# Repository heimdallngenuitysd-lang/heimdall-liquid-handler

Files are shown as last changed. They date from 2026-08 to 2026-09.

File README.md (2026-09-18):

Heimdall is a low-cost, open-source automated liquid-handling platform developed by repurposing a Creality Ender-series FDM 3D printer. The system retains the printer's Cartesian motion architecture while integrating a modular 3D-printed pipetting mechanism, an ESP32-based actuator controller, and host-side software for automated liquid-handling workflows.

A key feature of Heimdall is its vision-language model (VLM)-based closed-loop pipette-volume verification system. A camera captures the pipette volume display, and the VLM interprets the displayed setting. If the measured state differs from the requested target, the system automatically applies corrective actuation and repeats the verification process until the target setting is reached.

The platform supports:

Automated Cartesian positioning using G-code and the existing printer controller.
Programmable pipette-volume adjustment using the repurposed extruder stepper motor.
Automated aspiration, dispensing, blowout, and plunger control using an ESP32 and TB6612FNG motor driver.
Closed-loop visual verification and correction of pipette volume settings using Gemini 2.5 Flash.
Interchangeable fixtures for pipettes, labware, pipette tips, and camera positioning.
Host-side control through a Python-based graphical user interface.

The repository contains the software, firmware, control scripts, hardware-related files, and supporting documentation required to reproduce and operate the Heimdall liquid-handling platform.

Heimdall was developed as an accessible automation platform for laboratory workflows and as a foundation for integration into modular and self-driving laboratory systems.

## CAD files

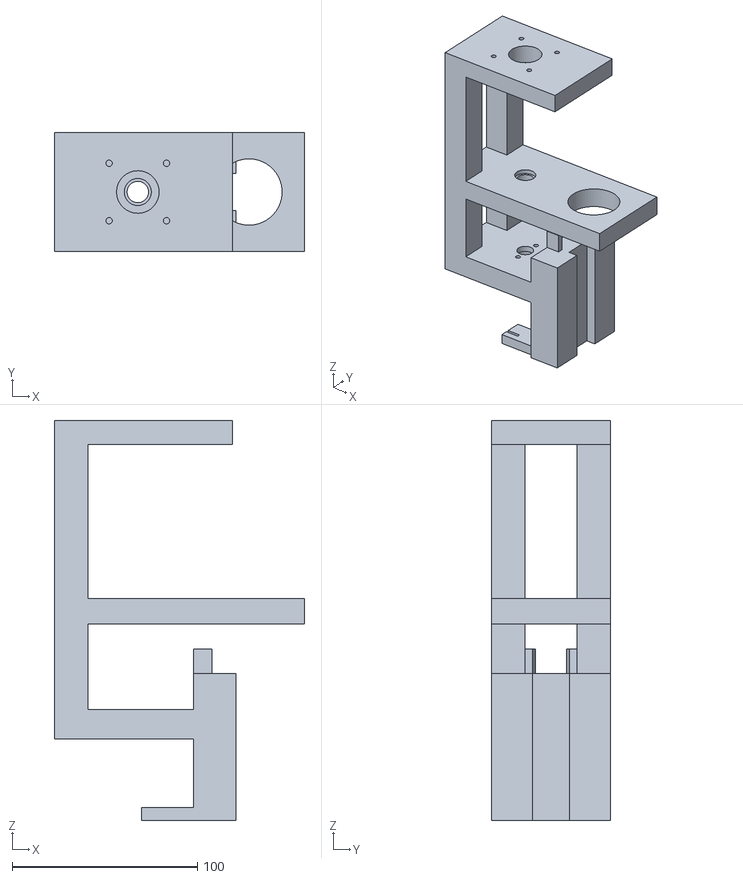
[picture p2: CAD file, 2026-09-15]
Hardware/3D Printing Files/Frame.stl
135.0 x 64.0 x 216.0

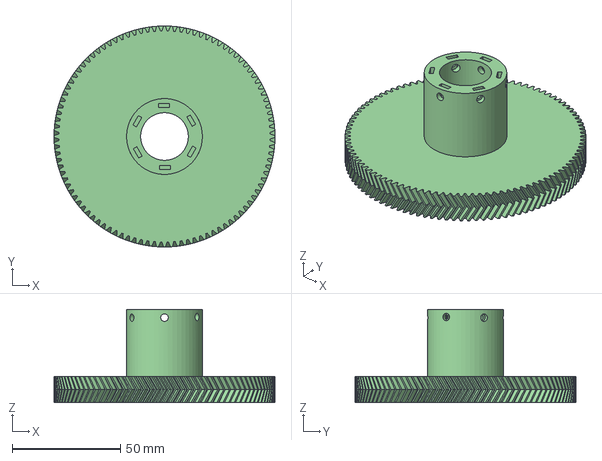
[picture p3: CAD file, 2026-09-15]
Hardware/Design Files/Driven Gear.step
102.0 x 102.0 x 43.0 mm

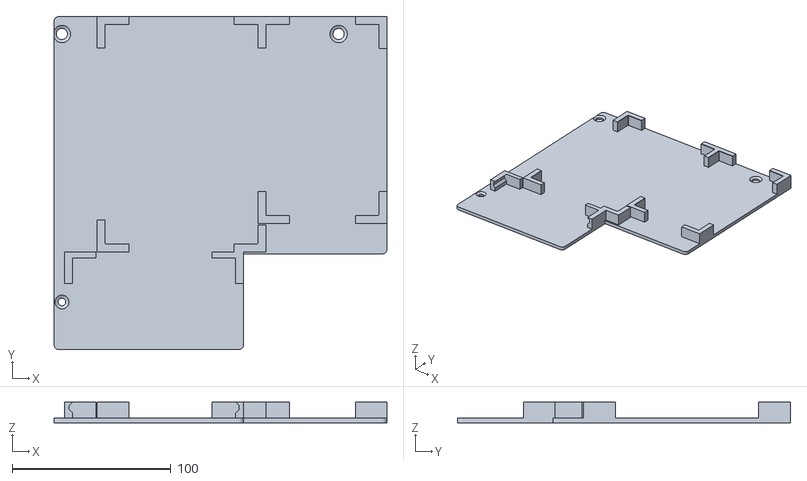
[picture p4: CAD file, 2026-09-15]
Hardware/3D Printing Files/Bed Plate.stl
210.0 x 210.1 x 13.0

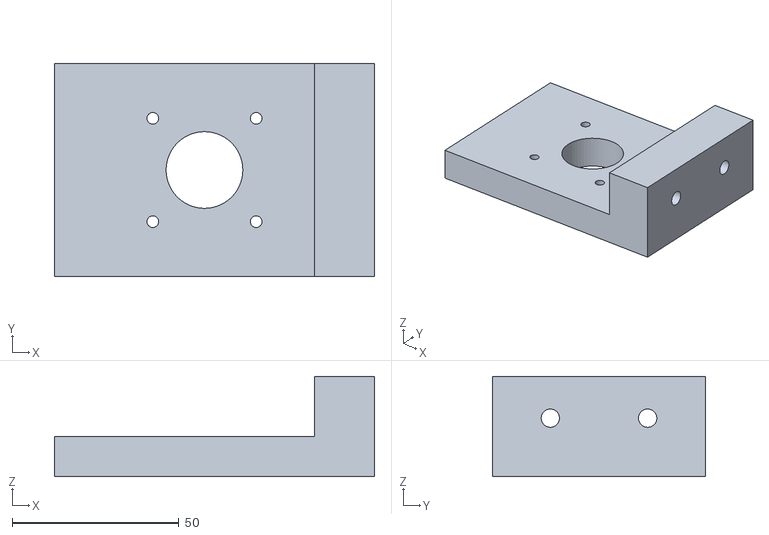
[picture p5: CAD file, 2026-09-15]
Hardware/3D Printing Files/Top Mounting Plate.stl
96.0 x 64.0 x 30.0

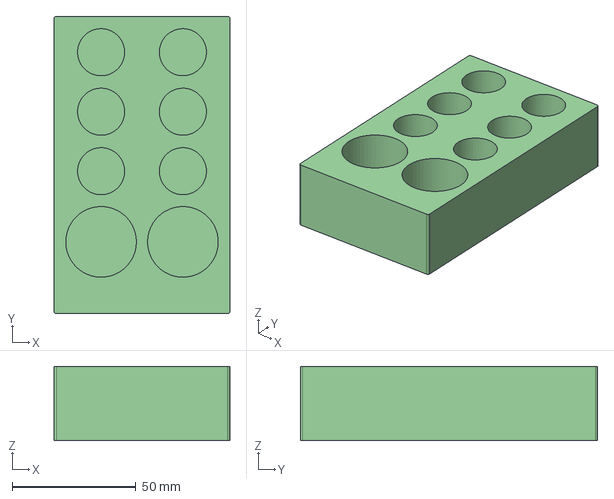
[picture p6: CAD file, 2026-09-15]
Hardware/Design Files/Stock Solution Holder.step
71.0 x 120.0 x 30.0 mm

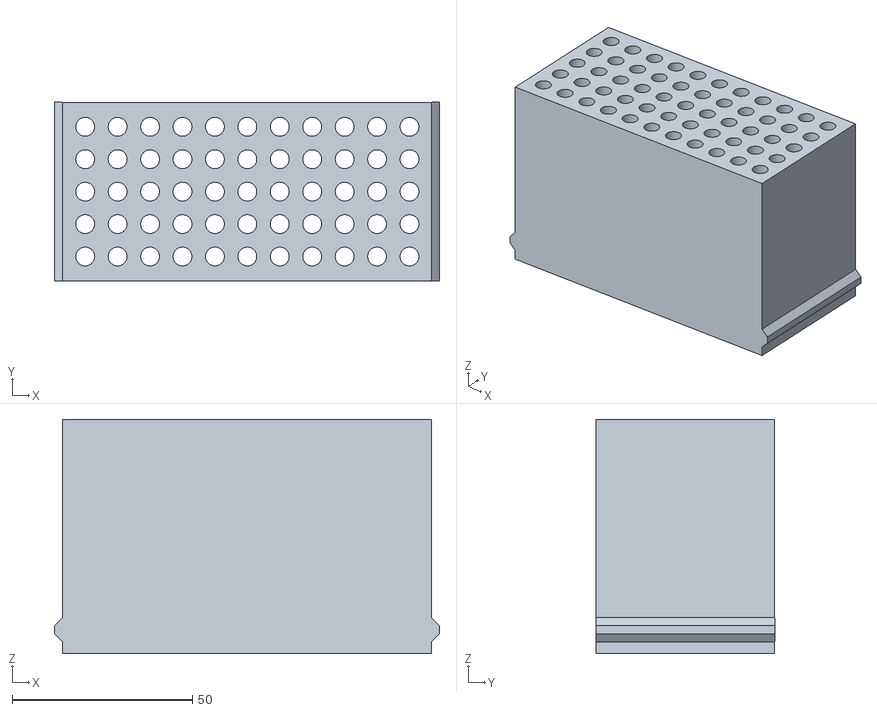
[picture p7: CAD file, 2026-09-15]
Hardware/3D Printing Files/Pipette Holder for 200microliter tips.stl
106.8 x 49.8 x 65.0

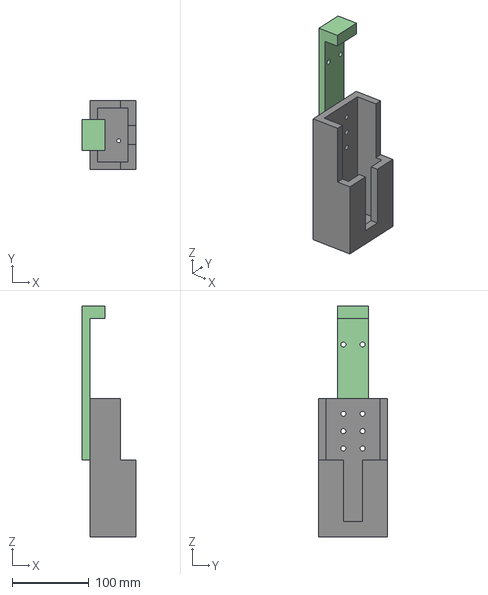
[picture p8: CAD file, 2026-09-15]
Hardware/Design Files/Pipette Tip Disposal Chamber Unit.step
70.0 x 90.0 x 300.0 mm
Tip ejector part
Disposal chamber

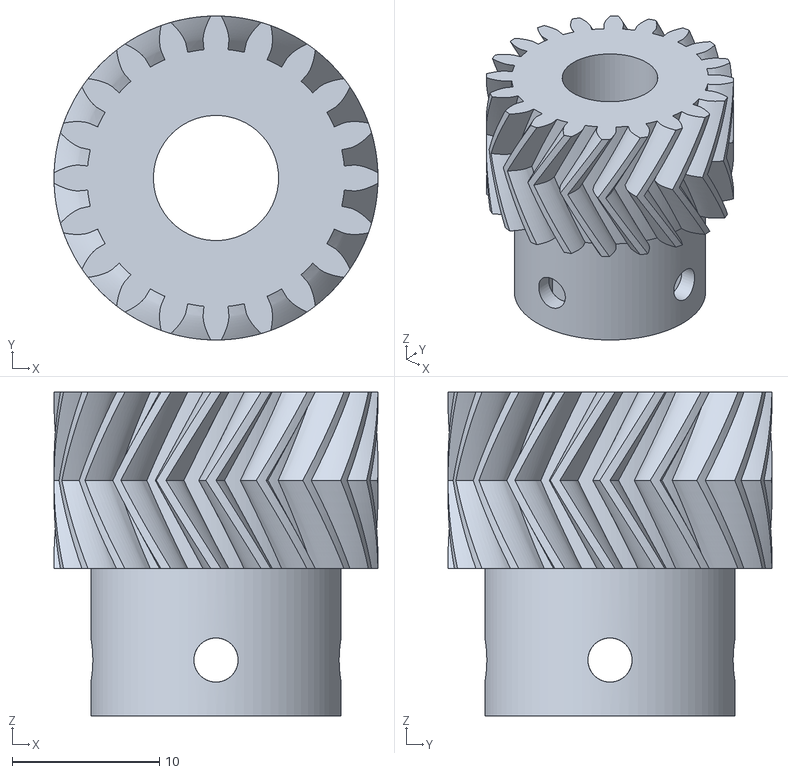
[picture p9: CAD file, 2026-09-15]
Hardware/3D Printing Files/Driver Gear.stl
22.0 x 22.0 x 22.0

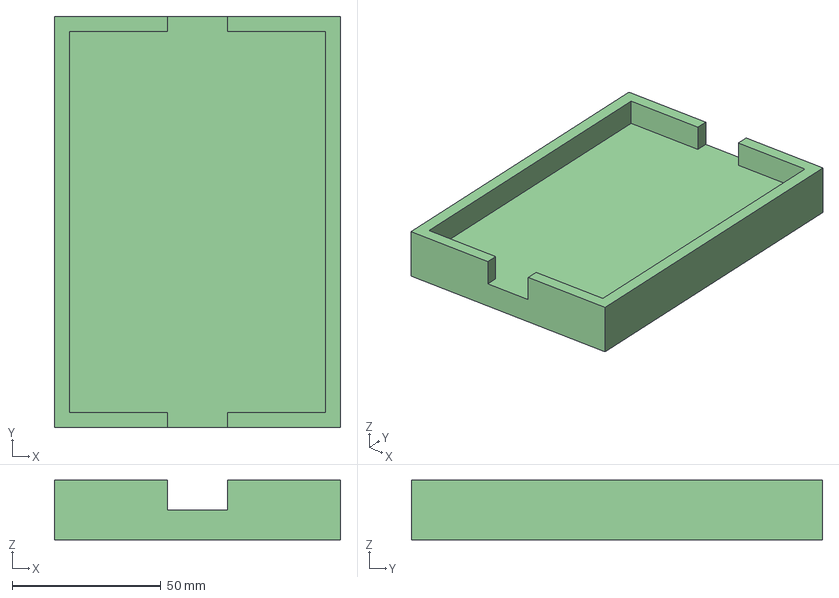
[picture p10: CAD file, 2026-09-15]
Hardware/Design Files/96 Well Plate Holder.step
96.0 x 138.0 x 20.0 mm

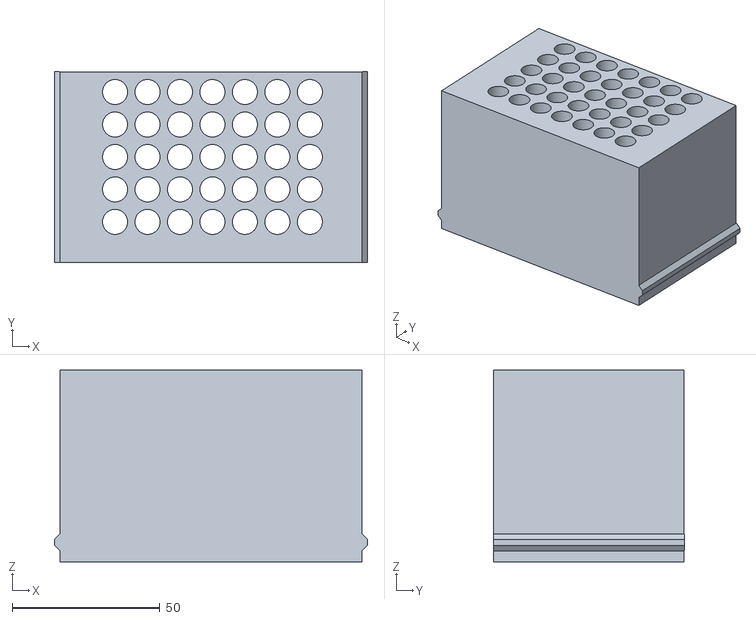
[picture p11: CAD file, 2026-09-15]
Hardware/3D Printing Files/Pipette Holder for 1000microliter tips.stl
106.0 x 64.8 x 65.0

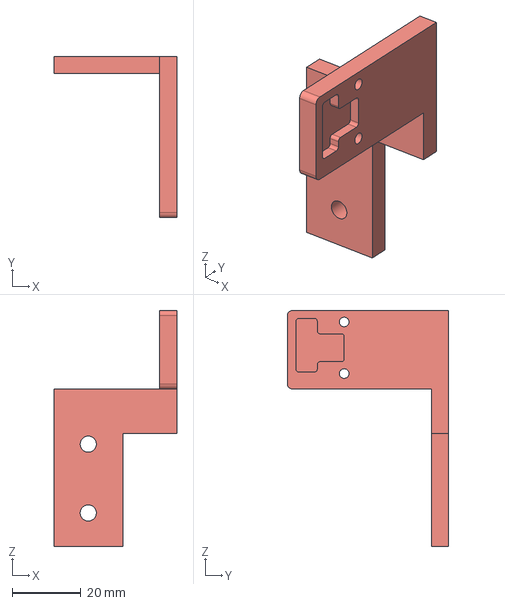
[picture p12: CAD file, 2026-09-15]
Hardware/Design Files/Z axis Limit Switch Holder.step
35.6 x 46.9 x 68.6 mm

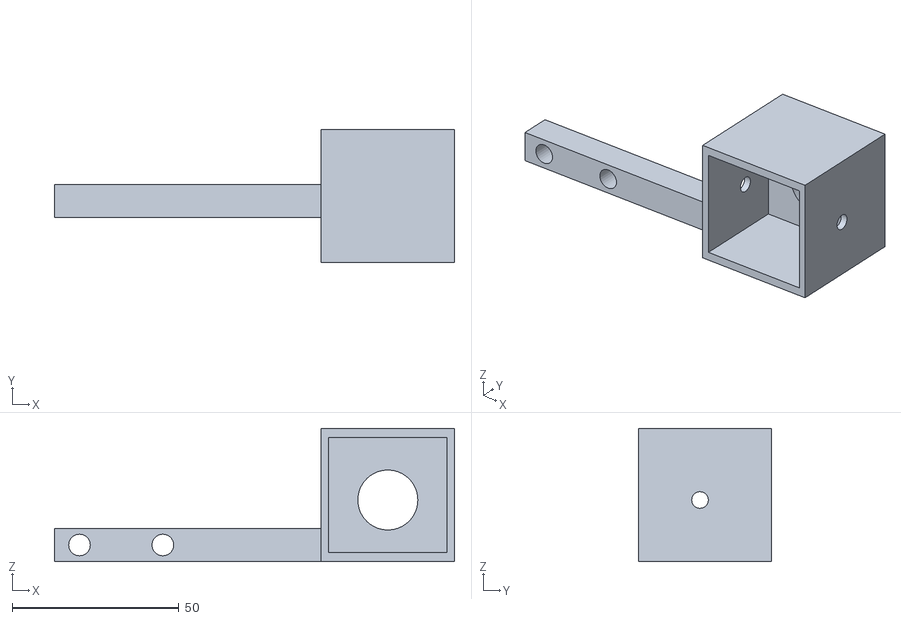
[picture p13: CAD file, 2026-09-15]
Hardware/3D Printing Files/Camera Mount.stl
120.0 x 40.0 x 40.0

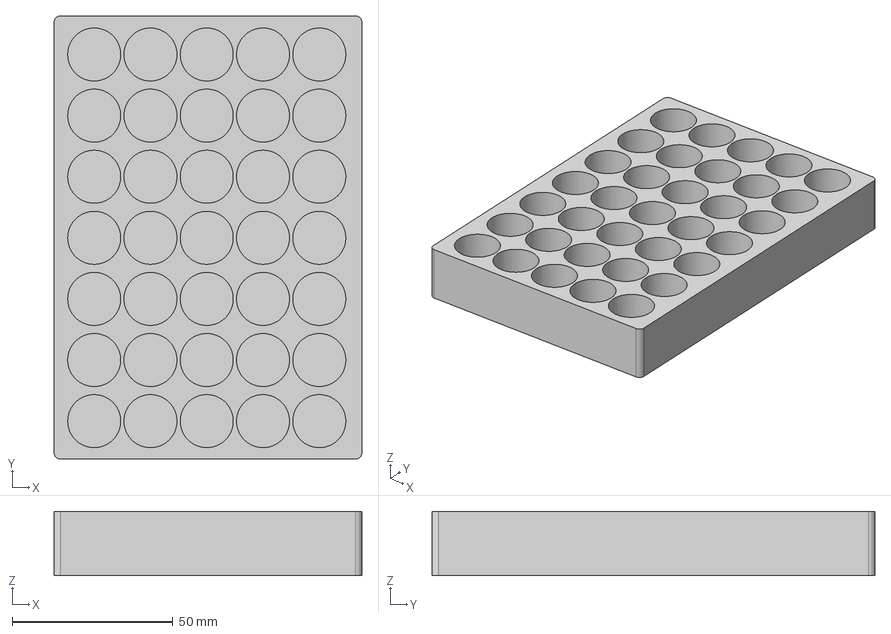
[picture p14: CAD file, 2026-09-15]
Hardware/Design Files/4ml Vial Holder.step
95.8 x 137.8 x 20.0 mm

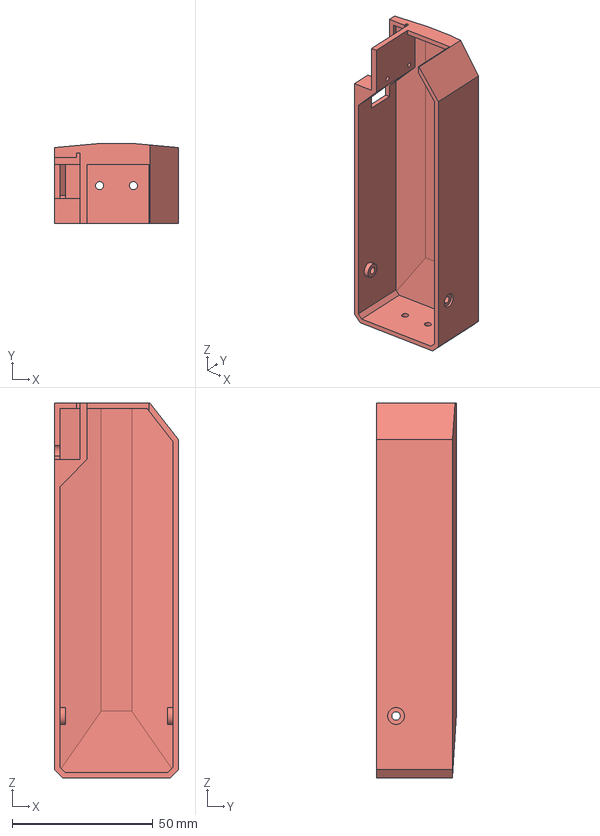
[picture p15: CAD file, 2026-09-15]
Hardware/Design Files/X axis Limit Switch Holder.step
44.0 x 28.5 x 133.0 mm

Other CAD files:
Hardware/Design Files/Frame.step
Hardware/3D Printing Files/Pipette Tip Disposal Chamber Unit (Tip Ejector Part).stl
Hardware/Design Files/Bed Plate.step
Hardware/3D Printing Files/Stock Solution Holder.stl
Hardware/3D Printing Files/4ml Vial Holder.stl
Hardware/3D Printing Files/96 Well Plate Holder.stl
Hardware/3D Printing Files/Driven Gear.stl
Hardware/3D Printing Files/Holder for 15ml Falcon tubes and 2ml Centrifuge tubes.stl
Hardware/3D Printing Files/Pipette Tip Disposal Chamber Unit (Disposal Chamber).stl
Hardware/3D Printing Files/X axis Limit Switch Holder.stl
Hardware/3D Printing Files/Z axis Limit Switch Holder.stl
Hardware/Design Files/Camera Mount.step
Hardware/Design Files/Driver Gear.step
Hardware/Design Files/Holder for 15ml Falcon tubes and 2ml Centrifuge tubes.step
Hardware/Design Files/Pipette Holder for 1000microliter tips.step
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

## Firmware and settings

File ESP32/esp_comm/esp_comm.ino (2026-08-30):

#include <ArduinoJson.h>

const int ENA  = 23;
const int AIN1 = 14;
const int AIN2 = 22;

// ESP32 PWM
const int pwmChannel = 0;
const int pwmFreq = 5000;
const int pwmResolution = 8;   // 0-255
int last_id = -1;

// Watchdog timer
unsigned long lastCommandTime = 0;
const unsigned long TIMEOUT_MS = 7000;

// Global speed
int currentPwmSpeed = 255;

void coastStop() {
  ledcWrite(ENA, 0);
  digitalWrite(AIN1, LOW);
  digitalWrite(AIN2, LOW);
}

void extendStart() {
  digitalWrite(AIN1, HIGH);
  digitalWrite(AIN2, LOW);
  ledcWrite(ENA, currentPwmSpeed);
}

void retractStart() {
  digitalWrite(AIN1, LOW);
  digitalWrite(AIN2, HIGH);
  ledcWrite(ENA, currentPwmSpeed);
}

void extendFor(uint32_t ms) {
  extendStart();
  delay(ms);
  coastStop();
}

void retractFor(uint32_t ms) {
  retractStart();
  delay(ms);
  coastStop();
}

bool verifyChecksum(const String& rawJson) {
    String json = rawJson;
    json.trim();

    // Find "checksum":
    int keyPos = json.indexOf("\"checksum\"");
    if (keyPos < 0) {
        Serial.println("Missing checksum key");
        return false;
    }

    int colonPos = json.indexOf(':', keyPos);
    if (colonPos < 0) {
        Serial.println("Malformed checksum field");
        return false;
    }

    // Skip whitespace
    int valueStart = colonPos + 1;
    while (valueStart < json.length() && isspace(json[valueStart])) {
        valueStart++;
    }

    // Read numeric checksum
    int valueEnd = valueStart;
    while (valueEnd < json.length() && isdigit(json[valueEnd])) {
        valueEnd++;
    }

    if (valueStart == valueEnd) {
        Serial.println("Invalid checksum value");
        return false;
    }

    int receivedChecksum = json.substring(valueStart, valueEnd).toInt();

    // Replace checksum digits with 0
    String modified =
        json.substring(0, valueStart) +
        "0" +
        json.substring(valueEnd);

    String calculatedHex = calculateChecksum(modified);

    char receivedHex[3];
    sprintf(receivedHex, "%02X", receivedChecksum);

    return calculatedHex.equalsIgnoreCase(receivedHex);
}

String calculateChecksum(const String& data) {
    uint8_t checksum = 0;

    for (size_t i = 0; i < data.length(); i++) {
        checksum ^= (uint8_t)data[i];
    }

    char buf[3];
    sprintf(buf, "%02X", checksum);

    return String(buf);
}

void sendJsonWithChecksum(JsonDocument& doc) {
    doc["checksum"] = 0;

    String payload;
    serializeJson(doc, payload);

    String checksumHex = calculateChecksum(payload);

    // If your protocol uses decimal checksum:
    doc["checksum"] = strtol(checksumHex.c_str(), nullptr, 16);

    payload = "";
    serializeJson(doc, payload);

    Serial.println(payload);
}

void setup() {
  Serial.begin(115200);

  pinMode(AIN1, OUTPUT);
  pinMode(AIN2, OUTPUT);

  // ESP32 PWM setup
  ledcAttach(ENA, pwmFreq, pwmResolution);

  retractStart();
  lastCommandTime = millis();

  // let boot messages finish
  delay(500);

  // clear any leftover junk (optional but helpful)
  while (Serial.available()) {
    Serial.read();
  }

  // READY handshake (MUST be JSON only)
  Serial.println("{\"status\":\"ready\"}");

}


void loop() {
  if (Serial.available()) {
    String msg = Serial.readStringUntil('\n');

    StaticJsonDocument<128> doc;
    DeserializationError err = deserializeJson(doc, msg);

    if (err) {
        return;  // Can't even determine the id
    }

    int id = doc["id"] | -1;

    if (!verifyChecksum(msg)) {
    StaticJsonDocument<64> ack;
    ack["ack"] = id;
    ack["status"] = "ok";
    ack["ok"] = false;

    sendJsonWithChecksum(ack);
    return;
    }

    StaticJsonDocument<64> ack;
    ack["ack"] = id;
    ack["status"] = "ok";
    ack["ok"] = true;

    sendJsonWithChecksum(ack);

    if (id == -1 | id <= last_id){
      return;
    }


    lastCommandTime = millis();

    bool direction = doc["direction"];   // true = extend
    uint32_t runTime = doc["time"];
    int speedPct = doc["speed"];

    speedPct = constrain(speedPct, 0, 100);
    currentPwmSpeed = map(speedPct, 0, 100, 0, 255);

    if (direction && runTime) {
      extendFor(runTime);
    } else {
      if (runTime) {
        retractFor(runTime);
      } else {
        retractStart();
      }
    }

    StaticJsonDocument<128> reply;
    reply["status"] = "ok";
    reply["direction"] = direction;
    reply["runtime"] = runTime;
    reply["id"] = id;

    sendJsonWithChecksum(reply);
    Serial.println();
    lastCommandTime = millis();
  }

  // watchdog: auto retract after no messages
  if (millis() - lastCommandTime >= TIMEOUT_MS) {
    currentPwmSpeed = 255;
    retractStart();
  }
}

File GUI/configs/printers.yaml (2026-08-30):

alfred:
  aspiration_actuation_time: 1120
  blowout_actuation_time: 400
  blowout_pause_time: 2000
  decimal_position: 0
  dispense_dwell_time: 2000
  dispose_actuate_z: 11
  dispose_initial_y: 15
  dispose_initial_z: 70
  dispose_start:
  - 150
  - 85
  - 246
  dispose_y: 17
  extruder: true
  max_vol: 1000
  min_vol: 100
  preset: null
  prime_dwell_time_after: 1000
  prime_dwell_time_before: 1
  vol_adjust_position:
  - 83.4
  - 65.0
  - 196.5
heimdall:
  aspiration_actuation_time: 1120
  blowout_actuation_time: 300
  blowout_pause_time: 2000
  decimal_position: 1
  dispense_dwell_time: 1600
  dispose_actuate_z: 11
  dispose_initial_y: 15
  dispose_initial_z: 70
  dispose_start:
  - 160
  - 85
  - 246
  dispose_y: 18
  extruder: true
  max_vol: 100
  min_vol: 10
  preset: null
  prime_dwell_time_after: 1000
  prime_dwell_time_before: 1
  vol_adjust_position:
  - 77.1
  - 86.3
  - 193.5
charlie:
  aspiration_actuation_time: 1120
  blowout_actuation_time: 400
  blowout_pause_time: 2000
  decimal_position: 1
  dispense_dwell_time: 50
  dispose_actuate_z: 12
  dispose_initial_y: 15
  dispose_initial_z: 40
  dispose_start:
  - 119.8
  - 82.9
  - 248.3
  dispose_y: 18
  extruder: true
  max_vol: 200
  min_vol: 20
  pipette-interval: 2
  preset: null
  prime_dwell_time_after: 1000
  prime_dwell_time_before: 1
  vol_adjust_position:
  - 43.1
  - 99.9
  - 217.5
cylie:
  aspiration_actuation_time: 1120
  blowout_actuation_time: 400
  blowout_pause_time: 2000
  decimal_position: 1
  dispense_dwell_time: 50
  dispose_actuate_z: 12
  dispose_initial_y: 15
  dispose_initial_z: 65
  dispose_start:
  - 160
  - 75
  - 246
  dispose_y: 18
  dobot_server: true
  extruder: true
  max_vol: 100
  min_vol: 10
  preset: null
  prime_dwell_time_after: 1000
  prime_dwell_time_before: 1
  vol_adjust_position:
  - 83.4
  - 65.0
  - 196.5

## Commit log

2026-08-30 Publish Heimdall liquid handler controller for the public repo.
    [12 Bottle Holder.step, 12 Bottle Holder.stl, 35 blank.csv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]
2026-09-10 Restore Confirm Volume button on the Assignment tab.
    Users can explicitly apply the volume field again without bringing back the removed checkbox options.
